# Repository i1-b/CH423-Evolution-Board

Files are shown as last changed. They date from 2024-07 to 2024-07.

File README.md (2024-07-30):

# CH423-Evolution-Board

Evolution board for cost effective I/O expansion operating via 2-wire serial interface.<br> 
It’s great solution for projects based on devices with low pin count. 
Such as ESP8266 /ESP8685.

The evolution board designed for CH423 in SOP28 package: https://www.wch-ic.com/products/CH423.html
<br>Datasheet: https://github.com/i1-b/CH423-Evolution-Board/blob/main/CH423DS1.PDF
<br>Or: https://www.wch-ic.com/downloads/CH432DS1_PDF.html

<h2>Overview</h2>

The CH423 is a universal remote I/O expansion chip with a two-wire serial interface. CH423 provides 8 bidirectional input and output pins and 16 general-purpose output pins to support input level change interrupt. CH423 built-in current drive circuit can statically drive 24 LED tubes or dynamically drive 128 LEDs (equivalent to 16 digital) Tube); CH423 exchanges data with a single-chip microcomputer through a 2-wire serial interface. 

<picture>
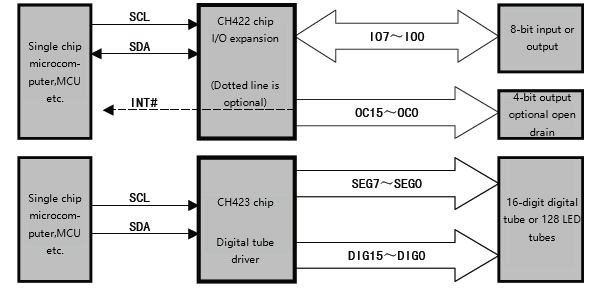
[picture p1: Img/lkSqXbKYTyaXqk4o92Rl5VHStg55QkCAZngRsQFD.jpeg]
   
</picture>

<h2>Features</h2>

    • 8 general-purpose input and output pins GPIO and 16 general-purpose output pin GPOs are remotely extended through a two-wire serial interface. 
    • Built-in current drive stage, continuous drive current is not less than 15mA, OC pin output 1/16 pulse sink current is not less than 120mA. 
    • The static display drive mode supports 24 LEDs or 3 LEDs. 
    • The time-sharing dynamic scanning display drive mode supports 128 LEDs or 16-bit common cathode digital tubes, and supports brightness control. 
    • The bidirectional I/O pin has an interrupt function when the input level changes in the input mode, and the interrupt output is active low. 
    • The 16 general-purpose output pins can be selected for push-pull output or open-drain output. 
    • Supports 3V ~ 5V power supply voltage, supports low-power sleep, can be awakened by input level changes. 
    • High-speed 2-wire serial interface with clock speeds from 0 to 1MHz, compatible with two-wire I2C bus, saving pins.

<h2>Schematic</h2>
https://github.com/i1-b/CH423-Evolution-Board/blob/main/CH423_ev.pdf

<h2>PCB Design</h2>

Repository contains:<br>
<b>/CH423_ev</b>    KiCAD PCB Design Project, including schematic and pcb files.
<br><b>/Prod</b>    GERBER files; drl file also included.

<picture>
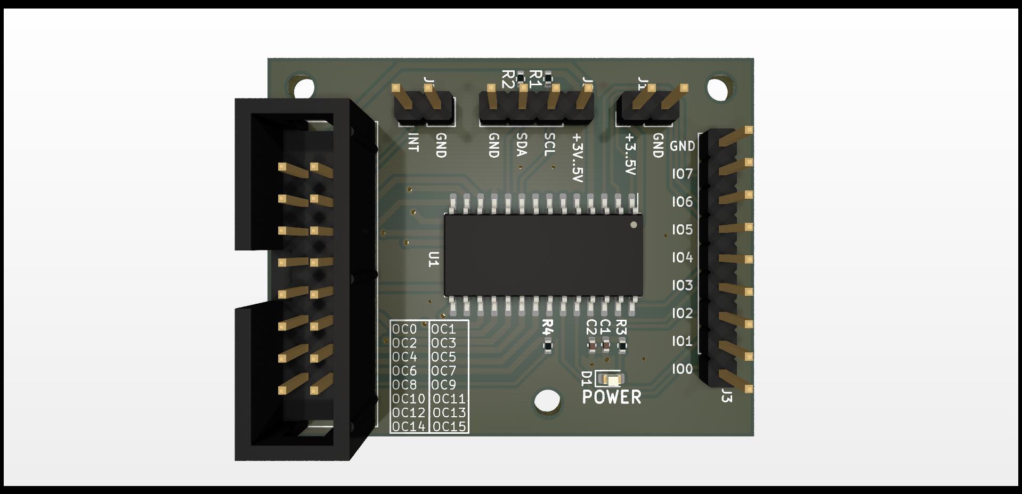
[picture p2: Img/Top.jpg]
   
</picture>

<picture>
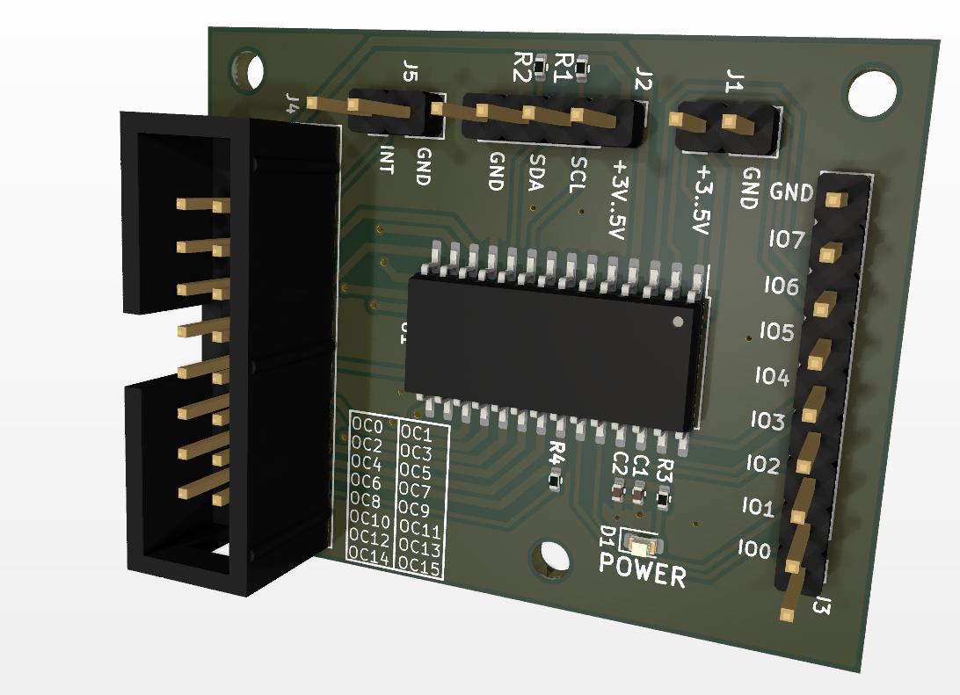
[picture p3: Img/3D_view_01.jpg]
   
</picture>

<picture>
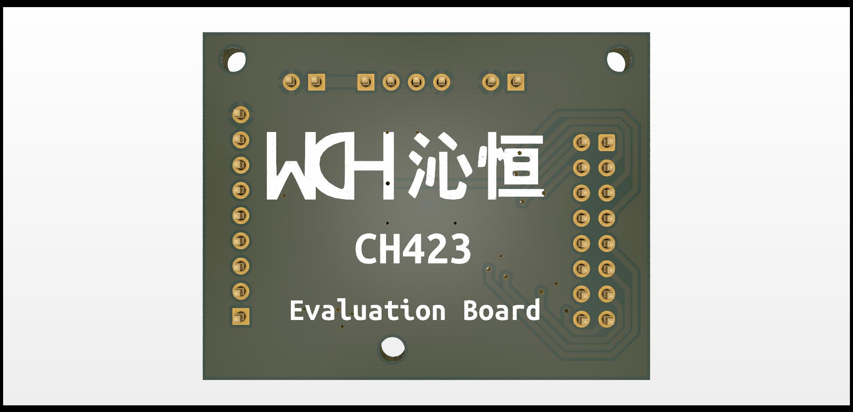
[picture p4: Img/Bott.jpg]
   
</picture>

<picture>
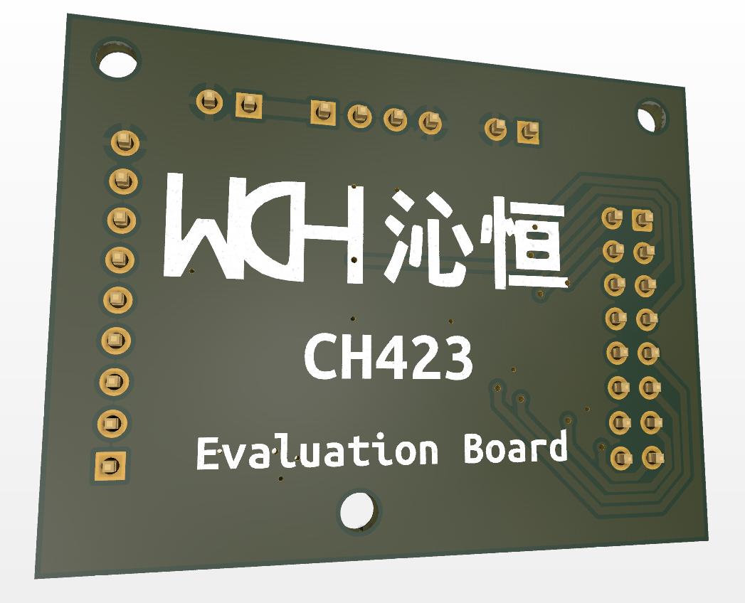
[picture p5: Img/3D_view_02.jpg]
   
</picture>

<h2>3D model</h2>
https://github.com/i1-b/CH423-Evolution-Board/blob/main/CH423_ev.step

<h2>Library</h2>

Library: https://github.com/Edragon/WCH-CH42X/tree/main/CH423EVT/EXAM

Arduino library: https://github.com/DFRobot/DFRobot_CH423 <br>
It works with I/O expansion only, dynamic scanning display drive mode unimplemented.

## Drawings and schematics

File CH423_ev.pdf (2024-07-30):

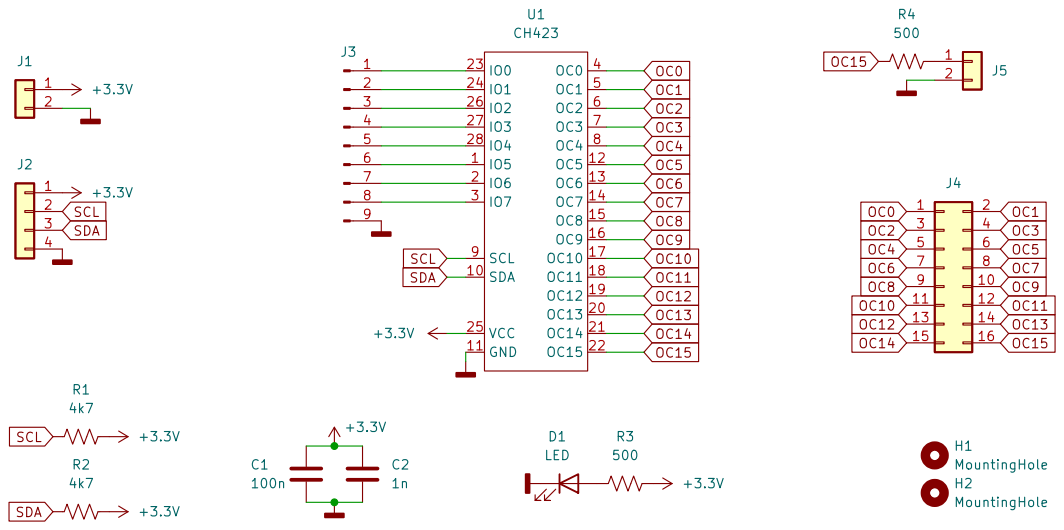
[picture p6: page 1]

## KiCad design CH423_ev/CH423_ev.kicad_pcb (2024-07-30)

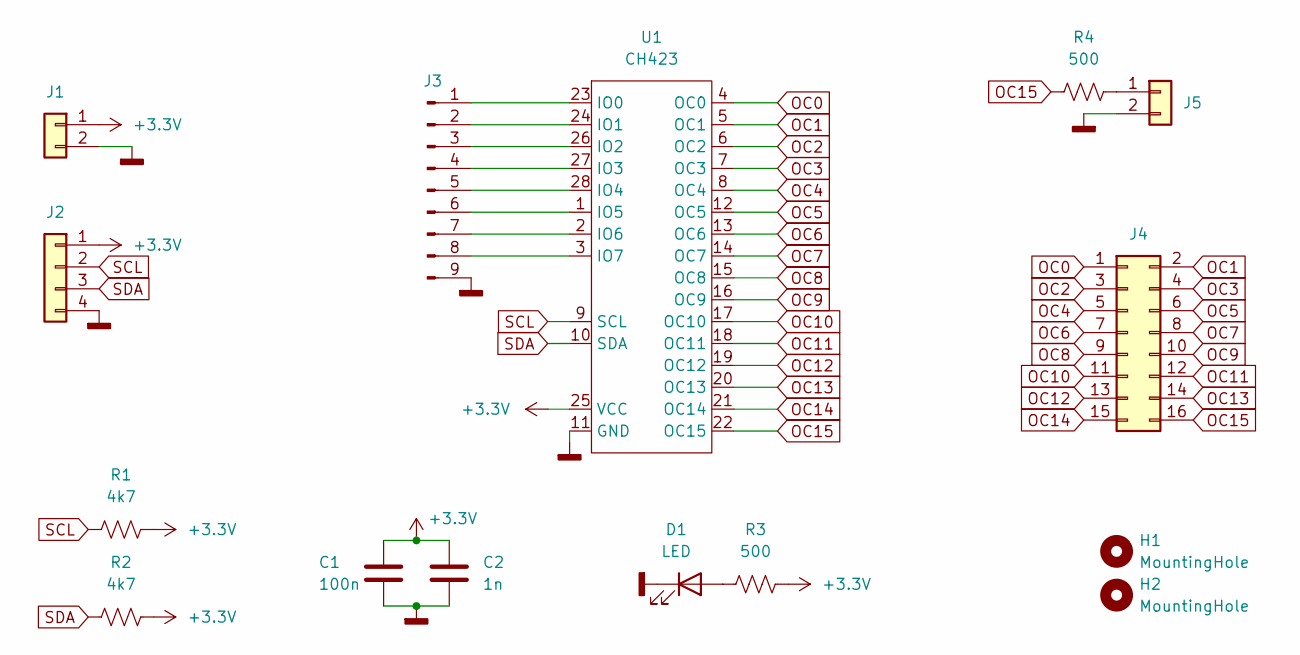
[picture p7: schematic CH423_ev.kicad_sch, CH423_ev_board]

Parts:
C1: 100n; C_0402_1005Metric
C2: 1n; C_0402_1005Metric
D1: LED; LED_0603_1608Metric
H1, H2: MountingHole; MountingHole_2.5mm
J1, J5: Conn_01x02; PinHeader_1x02_P2.54mm_Vertical
J2: Conn_01x04; PinHeader_1x04_P2.54mm_Vertical
J3: Conn_01x09_Male; PinHeader_1x09_P2.54mm_Vertical
J4: Conn_02x08_Odd_Even; IDC-Header_2x08_P2.54mm_Vertical
R1, R2: 4k7; R_0402_1005Metric
R3, R4: 500; R_0402_1005Metric
U1: CH423; SOIC-28W_7.5x17.9mm_P1.27mm

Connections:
+3V3: C1.1, C2.1, J1.1, J2.1, R1.2, R2.2, R3.2, U1.25 (VCC)
GNDD: C1.2, C2.2, D1.1 (K), J1.2, J2.4, J3.9, J5.2, U1.11 (GND)
unnamed: D1.2 (A), R3.1
unnamed: J3.1, U1.23 (IO0)
unnamed: J3.2, U1.24 (IO1)
unnamed: J3.3, U1.26 (IO2)
unnamed: J3.4, U1.27 (IO3)
unnamed: J3.5, U1.28 (IO4)
unnamed: J3.6, U1.1 (IO5)
unnamed: J3.7, U1.2 (IO6)
unnamed: J3.8, U1.3 (IO7)
unnamed: J5.1, R4.2
OC0: J4.1, U1.4 (OC0)
OC1: J4.2, U1.5 (OC1)
OC2: J4.3, U1.6 (OC2)
OC3: J4.4, U1.7 (OC3)
OC4: J4.5, U1.8 (OC4)
OC5: J4.6, U1.12 (OC5)
OC6: J4.7, U1.13 (OC6)
OC7: J4.8, U1.14 (OC7)
OC8: J4.9, U1.15 (OC8)
OC9: J4.10, U1.16 (OC9)
OC10: J4.11, U1.17 (OC10)
OC11: J4.12, U1.18 (OC11)
OC12: J4.13, U1.19 (OC12)
OC13: J4.14, U1.20 (OC13)
OC14: J4.15, U1.21 (OC14)
OC15: J4.16, R4.1, U1.22 (OC15)
SCL: J2.2, R1.1, U1.9 (SCL)
SDA: J2.3, R2.1, U1.10 (SDA)

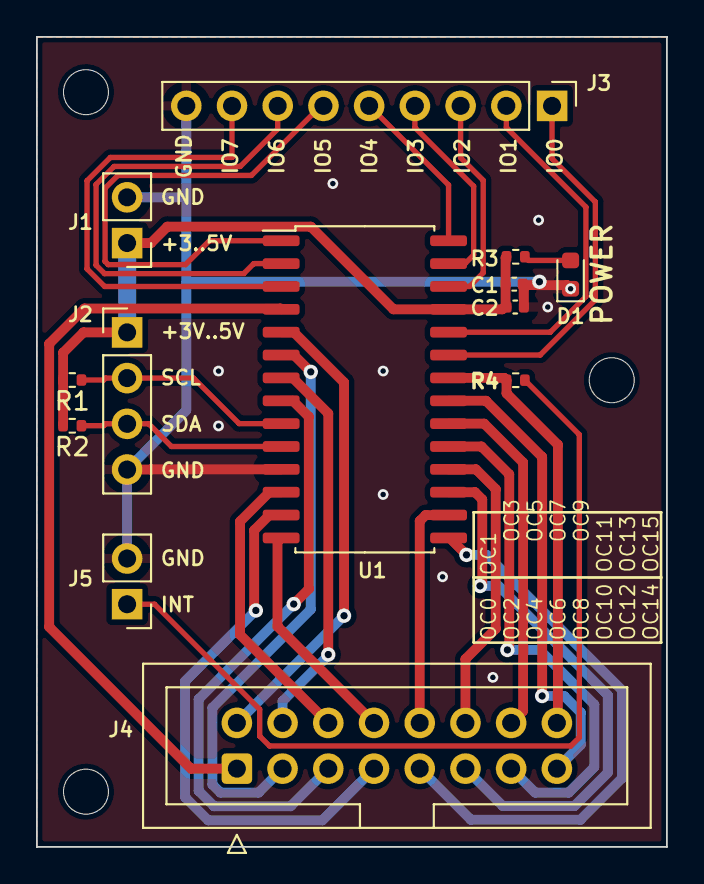
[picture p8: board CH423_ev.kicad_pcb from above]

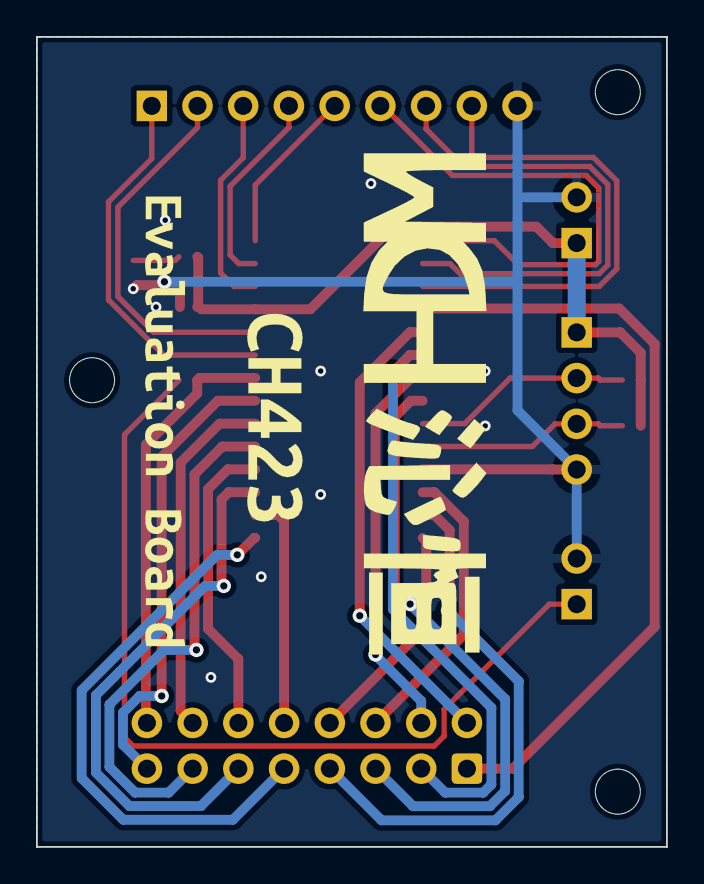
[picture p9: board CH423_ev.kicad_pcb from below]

Board: 2 copper layers, 35.0 x 45.0 mm, 18 parts (2 on the bottom side), 30 nets.

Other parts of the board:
H3: MountingHole; MountingHole_2.5mm
kibuzzard-61E6D3CC: G***; kibuzzard-61E6D3CC
kibuzzard-61E6D455: G***; kibuzzard-61E6D455
